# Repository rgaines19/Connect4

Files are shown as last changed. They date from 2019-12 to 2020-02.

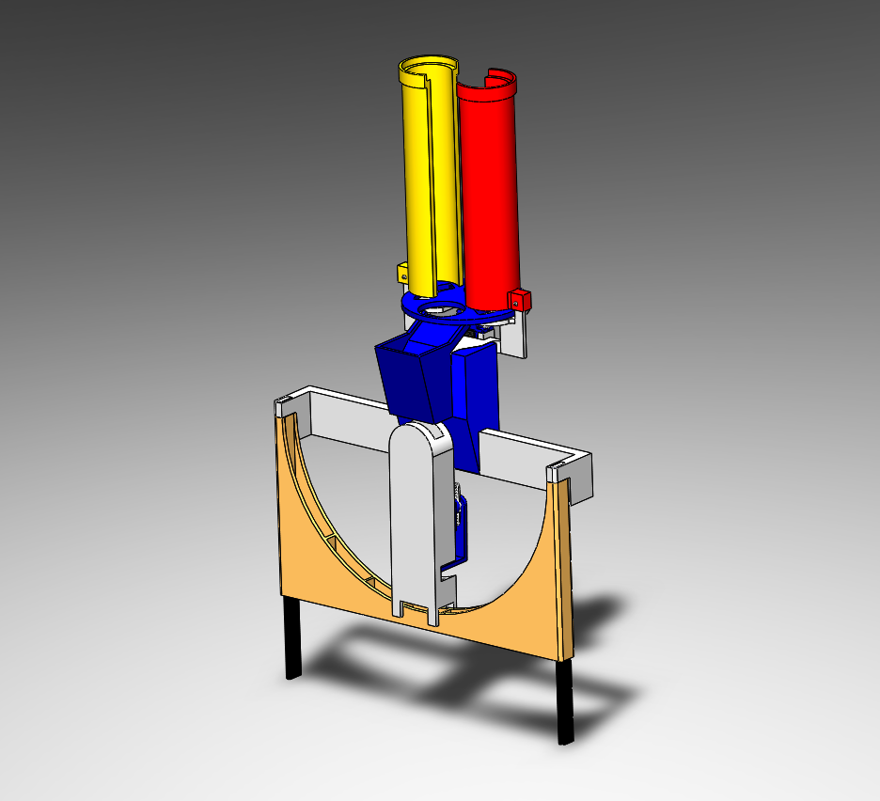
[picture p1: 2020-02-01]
Connect_4/Connect4_Robot.PNG

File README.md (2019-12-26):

# Connect4
This is a connect 4 project on arduino.
It will interface with an actual connect 4 gameboard by using push buttons and servos.

The game will have 3 difficultly levels.
Connect4.ino is the original C file for the game with 2 difficulties

Connect_4_Final_MEGA_Test_v2.ino is the complete working program that was used
at the Engineering Showcase.

Connect_4_Final_Due.ino is the program that has all three difficulty levels.
All it need is to port the servo commands and LED drivers and some status flags
to function properly.

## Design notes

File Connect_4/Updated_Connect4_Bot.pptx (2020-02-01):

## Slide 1

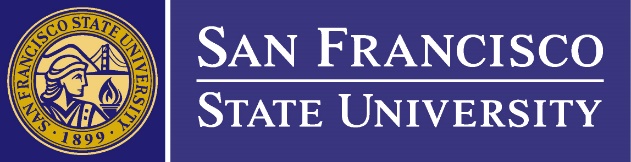
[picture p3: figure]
Image result

Connect 4 AI Bot
Team Members: Ronald Gaines (EE), Devin Perry (EE)
Academic Advisor: Dr. Thomas Holton

Introduction

This project arose from a conversation with a nurse that works in the children’s ward at UCSF. We decided to build a system that would brighten children’s days and get them curious about engineering.
Connect 4 is a two-player game where the objective is to connect four pieces in a row.

Objective

To create an AI-based robotic system to play against a human in Connect 4. It will be able to interact with a physical gameboard in order to provide a unique playing experience. In order to satisfy this objective, our system has to do the following:
- Detect when a human player makes a move
- Employ an AI algorithm to determine the system’s move
- Activate a robotic system to dispense game pieces into the correct column

Dispensing Mechanism

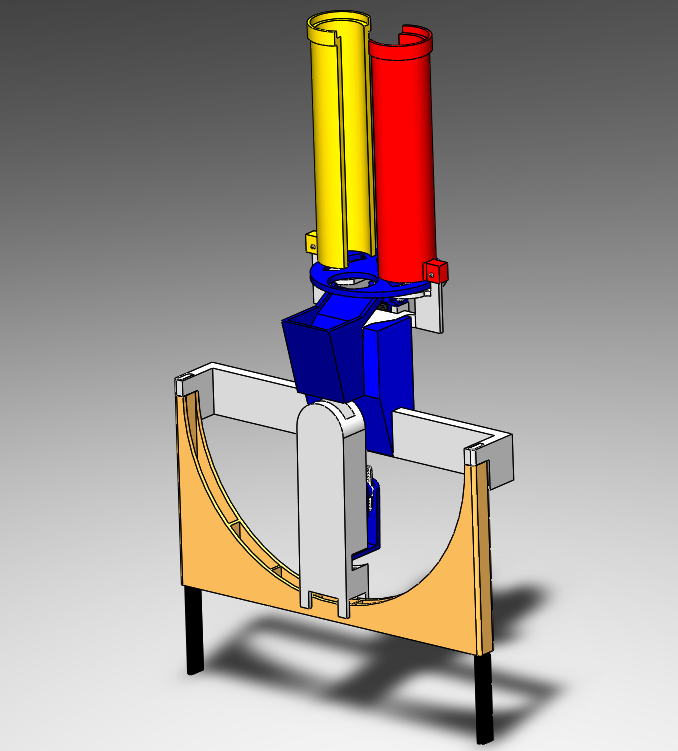
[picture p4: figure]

Flow Diagram

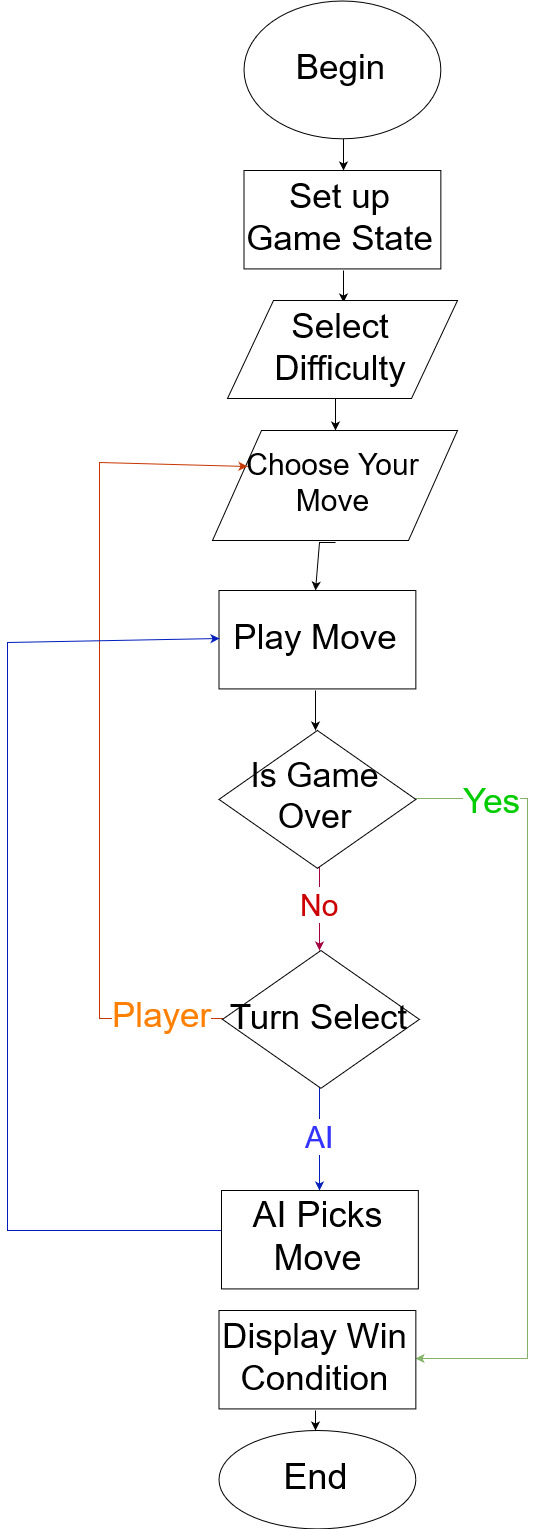
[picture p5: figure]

Discussion

- One the early problems we ran into was dealing with debouncing the arcade switches. Instead of debouncing seven signals, we used a 8:3 priority encoder to solve the problem. When sampling the button press, we send a signal to turn off the encoder which solved the bouncing problem.
- We had to switch from the Arduino Mega to the Arduino Due because the Mega didn’t have enough memory or computational power for our AI. The Due uses a 32 bit ARM processor.
- The dispensing mechanism was designed using SolidWorks, which allowed us to create the exact parts necessary.
- Manufacturing was done with 3D Printing in order to reduce costs and decrease time between design iterations.

Design

In order to meet our objective we used an Arduino Due. The Artificial Intelligence has 3 difficulty levels. The first level is a simple random number generator. The second level is our minimax algorithm with a search depth of 1. The third level is the minimax algorithm with a search depth of 4.
- We used arcade switches and LED’s for the human to interact with the game
- We 3D printed parts to create the dispensing mechanism
- We used 3 Servo motors to aid with dispensing the game pieces
- We used Minimax Algorithm with an evaluation function to create the AI system

Connectivity Diagram

AI Algorithm

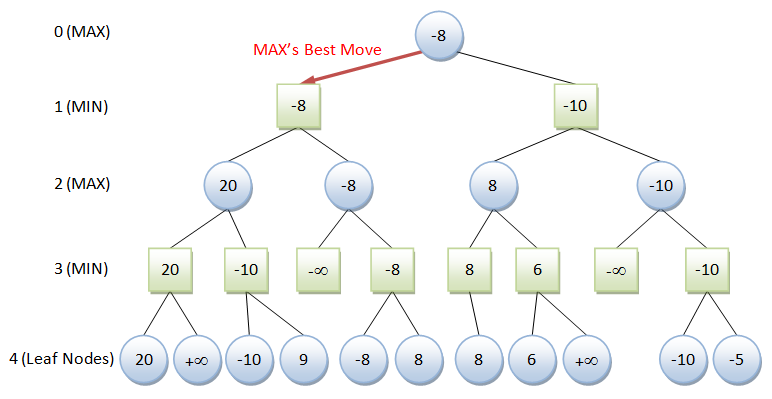
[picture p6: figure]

The minimax algorithm we used is a recursive AI algorithm for choosing the next move based on the position of the game pieces. The algorithm’s position evaluation determines how good each possible move is and attempts to minimize the possible maximum (worst-case) outcome. As the search depth increases, the better the AI’s decision becomes at the cost of computational time.

Future Work

- We would like to implement WIFI connectivity in order for two people to play each other from different rooms using two boards.
- We need to improve our evaluation functions to recognize some corner cases.
- We would like to implement Minimax algorithm with alpha-beta pruning in order to speed up the AI decision time.
- Implementing snap-fit connections would improve the building procedure of our dispensing mechanism
Acknowledgments: Our team would like to thank our advisor and mentor Dr. Holton for his assistance in the completion of this project.

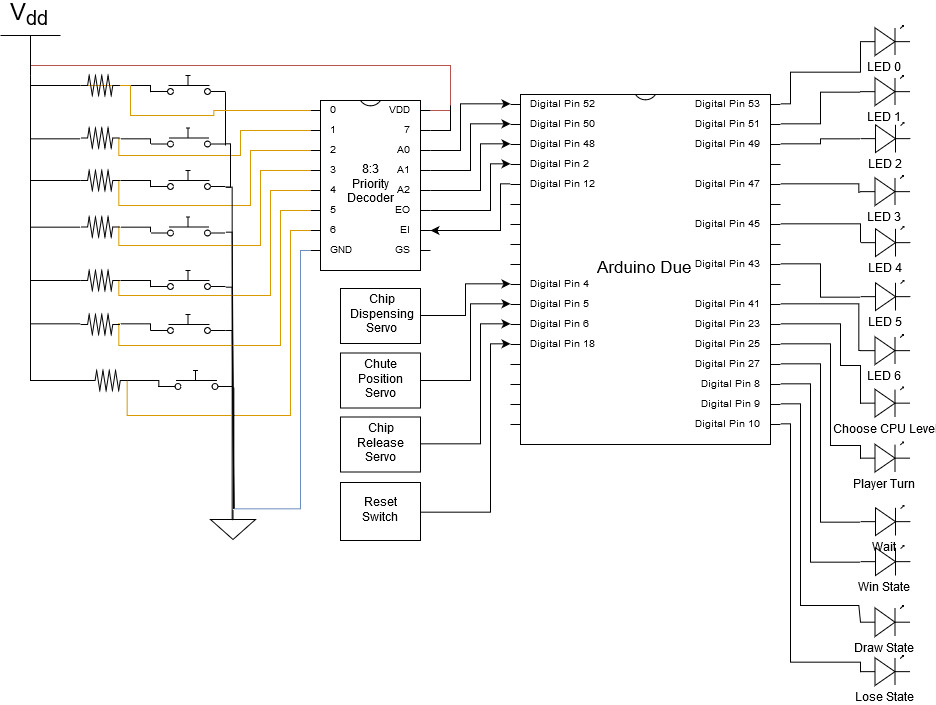
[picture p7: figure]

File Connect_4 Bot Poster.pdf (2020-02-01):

- We would like to implement WIFI connectivity in order for two people to play each other from different rooms using two boards.

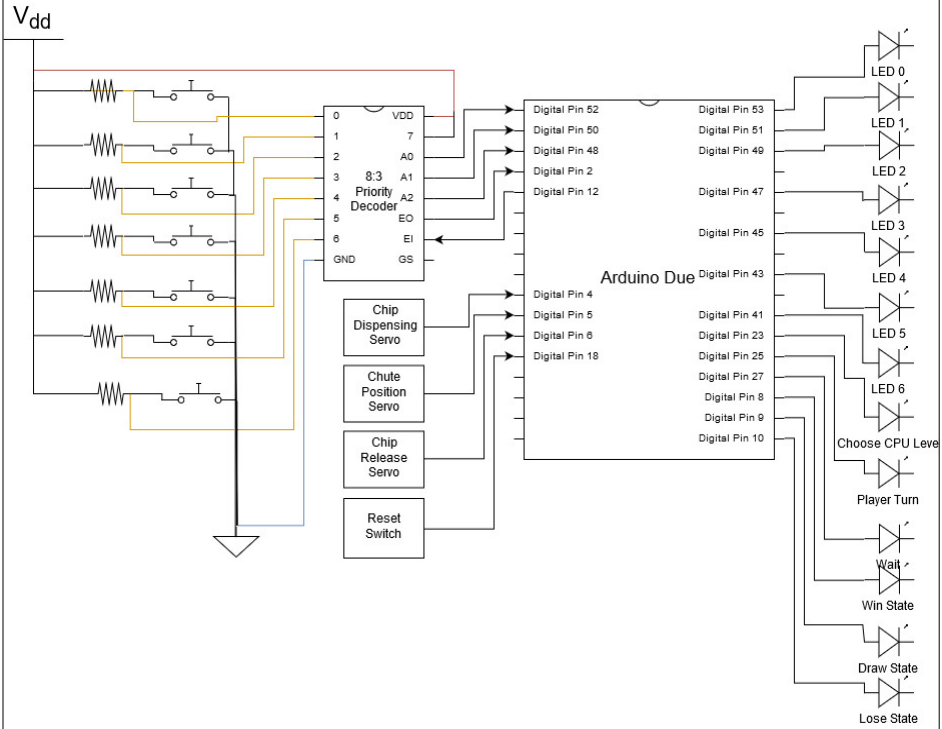
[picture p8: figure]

- We need to improve our evaluation functions to recognize some corner cases.
- We would like to implement Minimax algorithm with alpha-beta pruning in order to speed up the AI decision time.
- Implementing snap-fit connections would improve the building procedure of our dispensing mechanism

Acknowledgments: Our team would like to thank our advisor and mentor Dr. Holton for his assistance in the completion of this project.

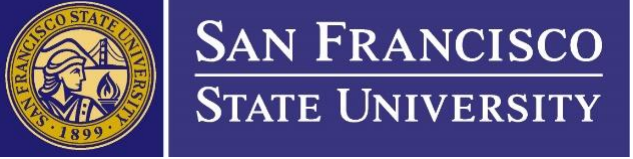
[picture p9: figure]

# Connect 4 AI Bot

Team Members: Ronald Gaines (EE), Devin Perry (EE) Academic Advisor: Dr. Thomas Holton

This project arose from a conversation with a nurse that works in the children’s ward at UCSF. We decided to build a system that would brighten children’s days and get them curious about engineering.
Connect 4 is a two-player game where the objective is to connect four pieces in a row.

In order to meet our objective we used an Arduino Due. The Artificial Intelligence has three difficulty levels.
The first level is a simple random number generator. The second level is our minimax algorithm with a search depth of one. The third level is the minimax algorithm with a search depth of four.
- We used arcade switches and LED’s for the human to interact with the game
- We 3D printed parts to create the dispensing mechanism
- We used three Servo motors to aid with dispensing the game pieces
- We used Minimax Algorithm with an evaluation function to create the AI system
- One the early problems we ran into was dealing with debouncing the arcade switches. Instead of debouncing seven signals, we used a 8:3 priority encoder to solve the problem. When sampling the button press, we send a signal to turn off the encoder which solved the bouncing problem.
- We had to switch from the Arduino Mega to the Arduino Due because the Mega didn’t have enough memory or computational power for our AI. The Due uses a 32-bit ARM processor.
- The dispensing mechanism was designed using SolidWorks, which allowed us to create the exact parts necessary.
- Manufacturing was done with 3D Printing in order to reduce costs and decrease time between design iterations.

## Design

## Introduction

To create an AI-based robotic system to play against a human in Connect 4. It will be able to interact with a physical gameboard in order to provide a unique playing experience. In order to satisfy this objective, our system has to do the following:

- Detect when a human player makes a move
- Employ an AI algorithm to determine the system’s move
- Activate a robotic system to dispense game pieces into the correct column

## Objective

## Discussion

## Future Work

Dispensing Mechanism | Flow Diagram

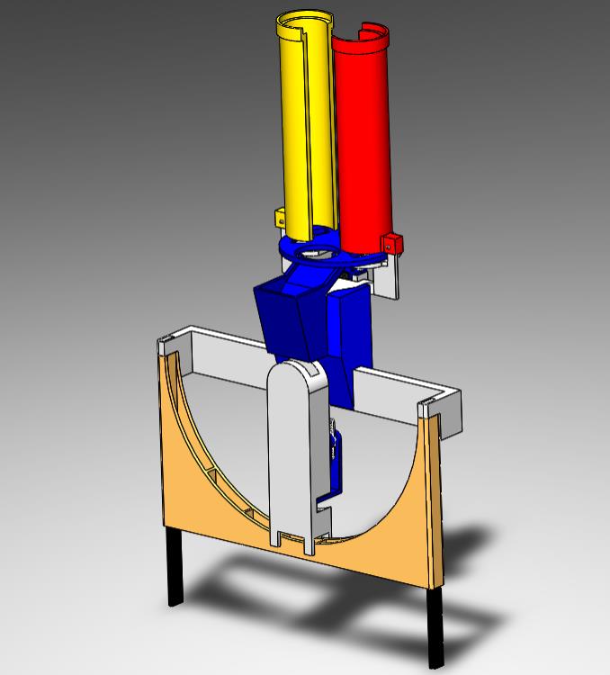
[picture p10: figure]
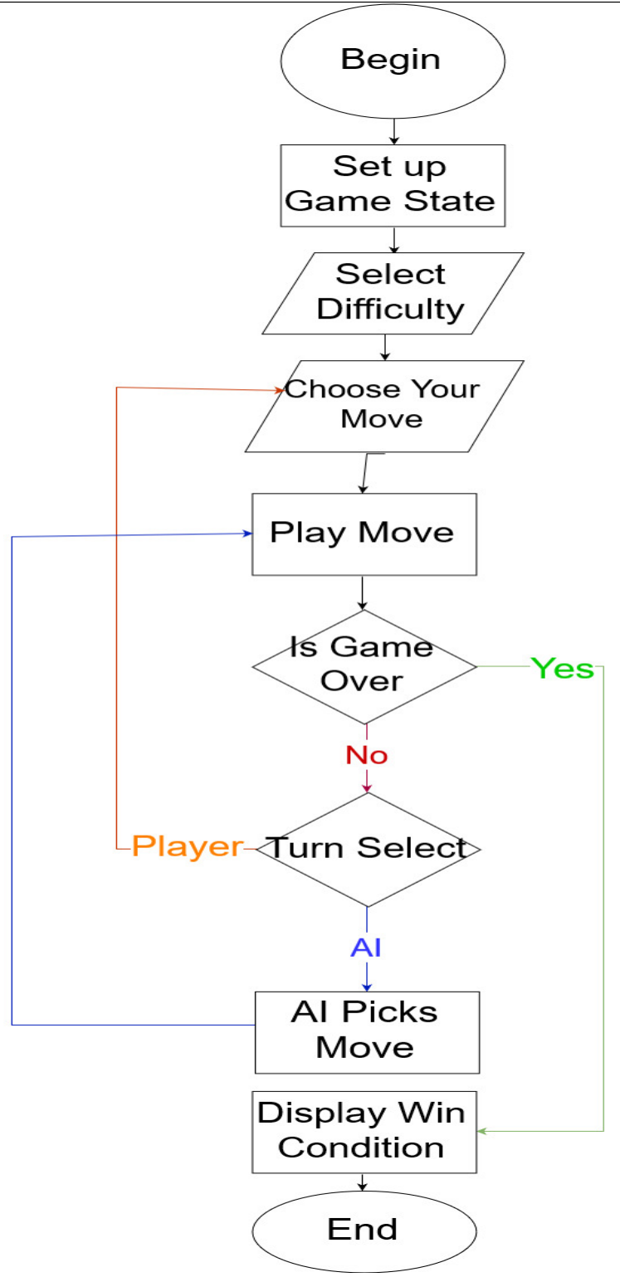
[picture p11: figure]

Connectivity Diagram | AI Algorithm

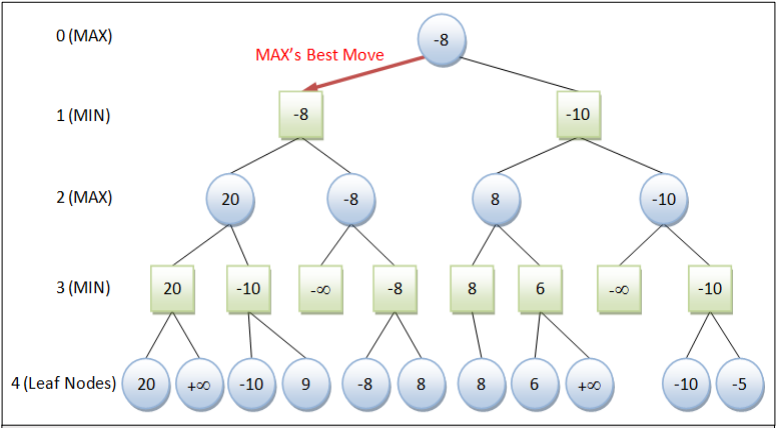
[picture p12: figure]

The minimax algorithm we used is a recursive AI algorithm for choosing the next move based on the position of the game pieces. The algorithm’s position evaluation determines how good each possible move is and attempts to minimize the possible maximum (worst-case) outcome. As the search depth increases, the better the AI’s decision becomes at the cost of computational time.

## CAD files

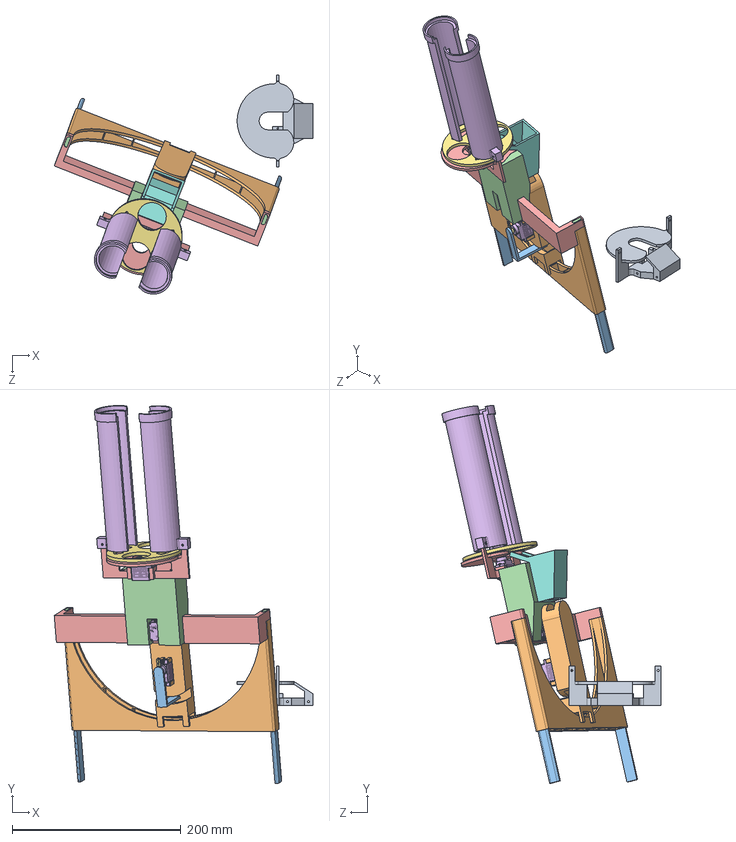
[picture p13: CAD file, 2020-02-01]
Connect_4/Connect4_Robot.SLDASM
306.7 x 448.4 x 260.1 mm
C4_Halfpipe
C4_Halfpipe Leg_NEW x 2
C4_ServoHolder Leg x 2
C4_ServoHolder
SG90 - Micro Servo 9g - Tower Pro.1 x 3
SG90 - Micro Servo 9g - Tower Pro.3 x 3
SG90 - Micro Servo 9g - Tower Pro.5 x 6
SG90 - Micro Servo 9g - Tower Pro.6 x 5
C4_Chute_3
C4_Gate
C4_Dispenser_Holder
Double_sided
Piece Holder Tube x 2
C4_Extractor
Slider Spacer Front

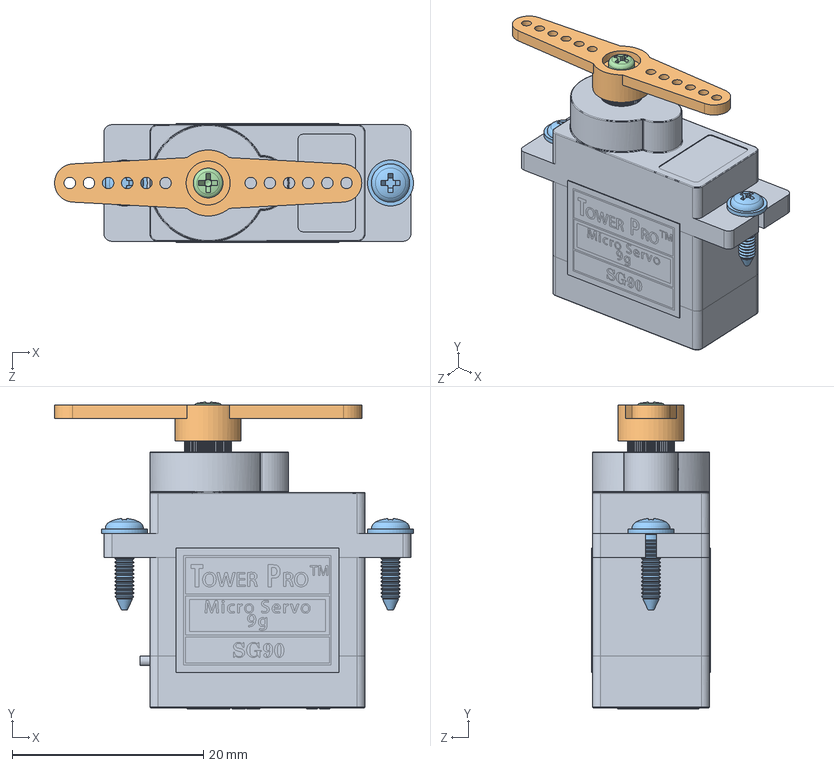
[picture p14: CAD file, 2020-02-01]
Connect_4/sg90-micro-servo-9g-tower-pro-1/SG90 - Micro Servo 9g - Tower Pro.SLDASM
37.5 x 32.0 x 12.4 mm
SG90 - Micro Servo 9g - Tower Pro.1
SG90 - Micro Servo 9g - Tower Pro.3
SG90 - Micro Servo 9g - Tower Pro.5 x 2
SG90 - Micro Servo 9g - Tower Pro.6

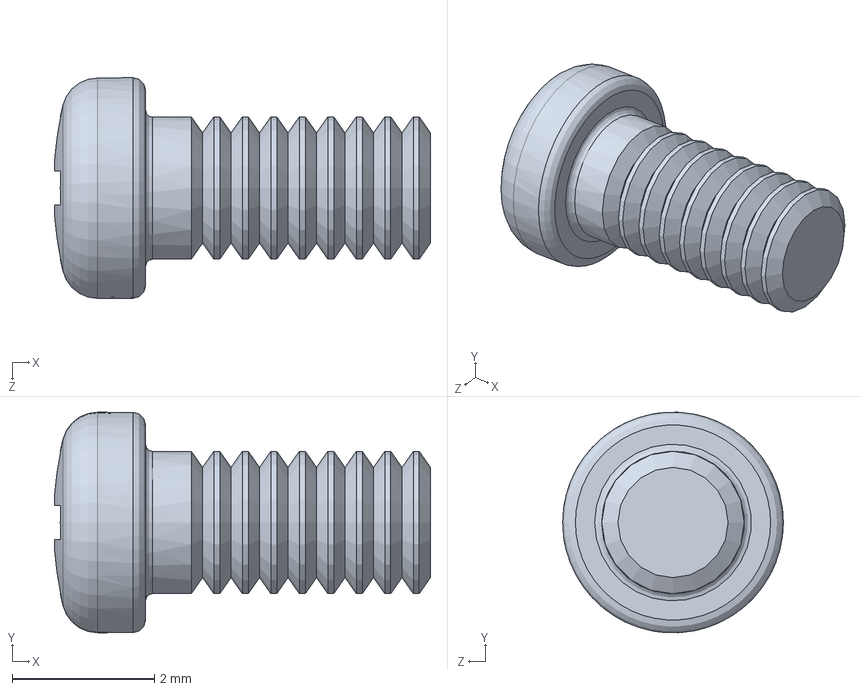
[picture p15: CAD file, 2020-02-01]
Connect_4/sg90-micro-servo-9g-tower-pro-1/SG90 - Micro Servo 9g - Tower Pro.6.SLDPRT
5.28 x 3.10 x 3.10 mm

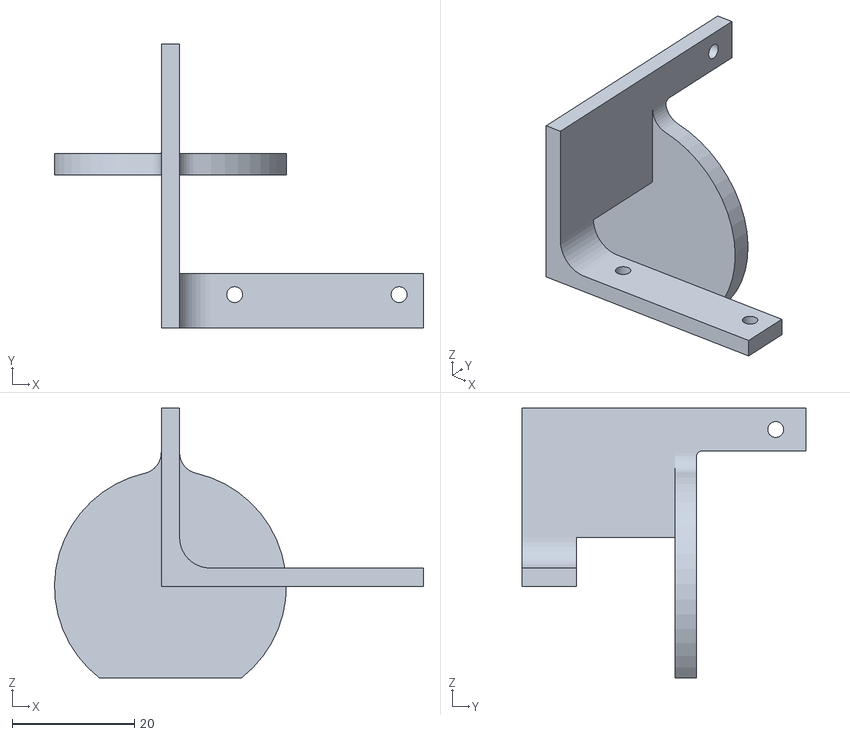
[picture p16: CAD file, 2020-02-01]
Connect_4/STL/C4_Piece Holder.STL
60.5 x 46.6 x 44.2

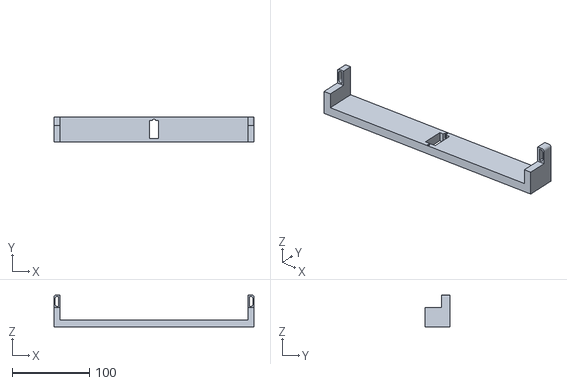
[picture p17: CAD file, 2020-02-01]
Connect_4/STL/C4_ServoHolder.STL
259.6 x 32.6 x 41.3

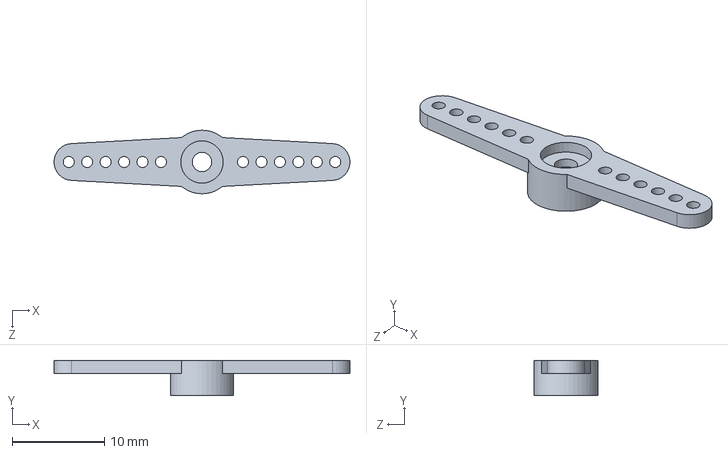
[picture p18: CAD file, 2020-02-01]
Connect_4/sg90-micro-servo-9g-tower-pro-1/SG90 - Micro Servo 9g - Tower Pro.3.SLDPRT
32.1 x 3.80 x 6.90 mm

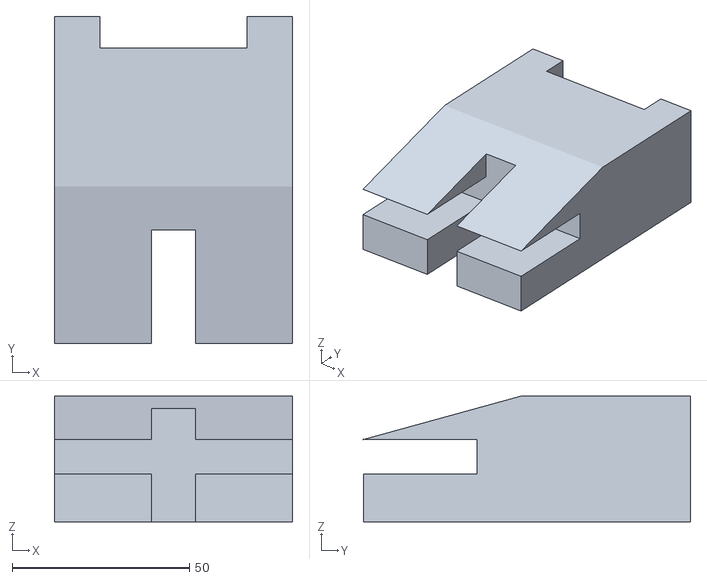
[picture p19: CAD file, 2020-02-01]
Connect_4/STL/C4_Dispenser_Holder.STL
67.1 x 92.3 x 35.4

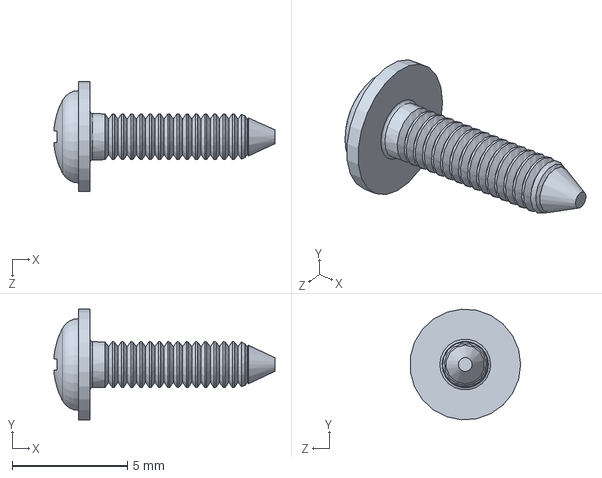
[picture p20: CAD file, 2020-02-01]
Connect_4/sg90-micro-servo-9g-tower-pro-1/SG90 - Micro Servo 9g - Tower Pro.5.SLDPRT
9.57 x 4.79 x 4.78 mm

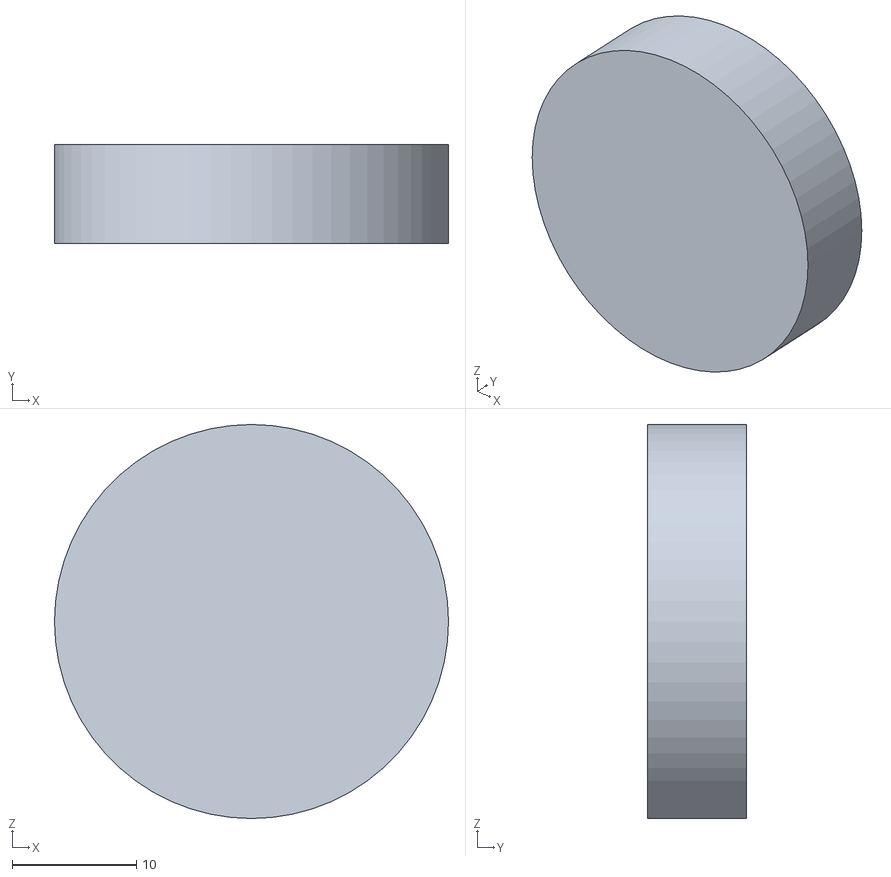
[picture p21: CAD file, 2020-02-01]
Connect_4/STL/Chip.STL
31.8 x 7.94 x 31.8

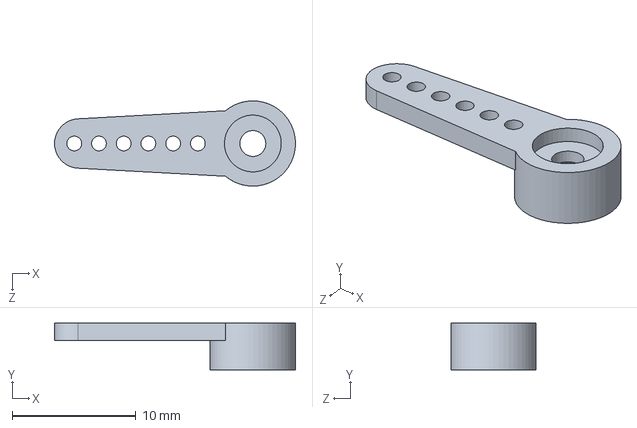
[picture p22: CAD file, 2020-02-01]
Connect_4/sg90-micro-servo-9g-tower-pro-1/SG90 - Micro Servo 9g - Tower Pro.2.SLDPRT
19.5 x 3.80 x 6.90 mm

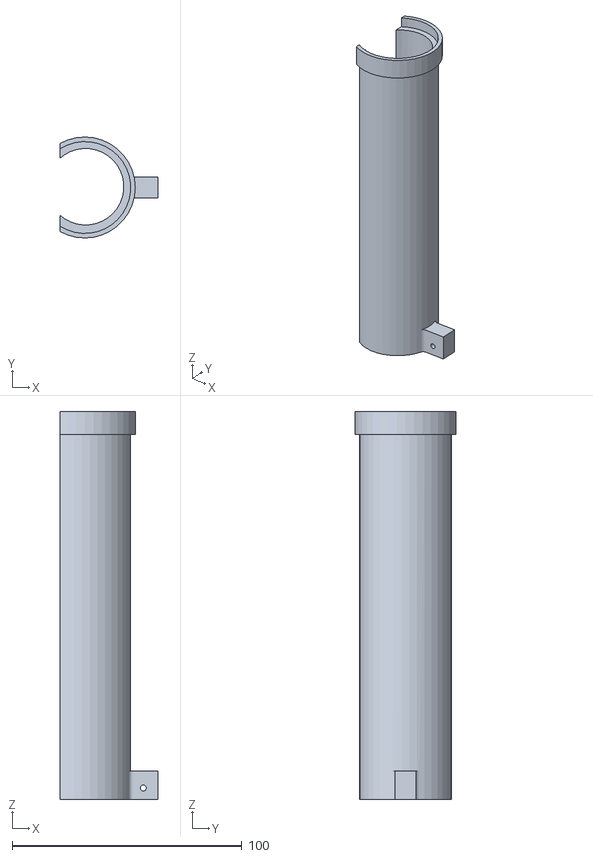
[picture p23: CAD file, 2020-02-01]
Connect_4/STL/C4_Piece Holder Tube.STL
42.9 x 44.0 x 169.0

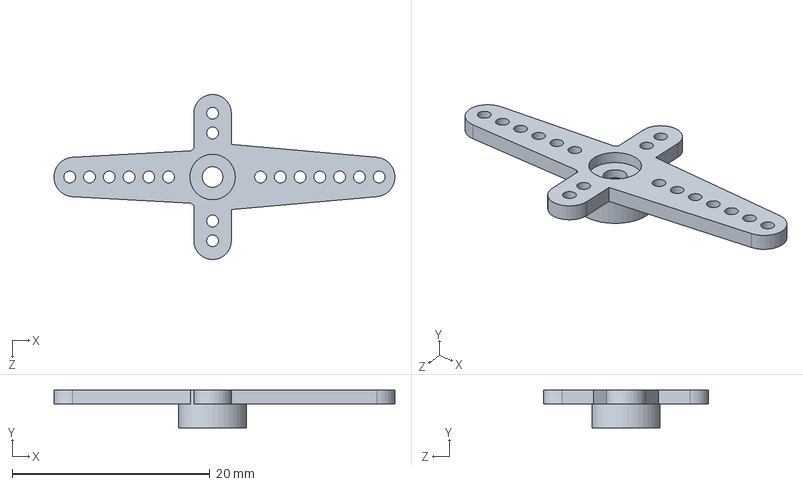
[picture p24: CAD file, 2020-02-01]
Connect_4/sg90-micro-servo-9g-tower-pro-1/SG90 - Micro Servo 9g - Tower Pro.4.SLDPRT
34.5 x 3.80 x 16.7 mm

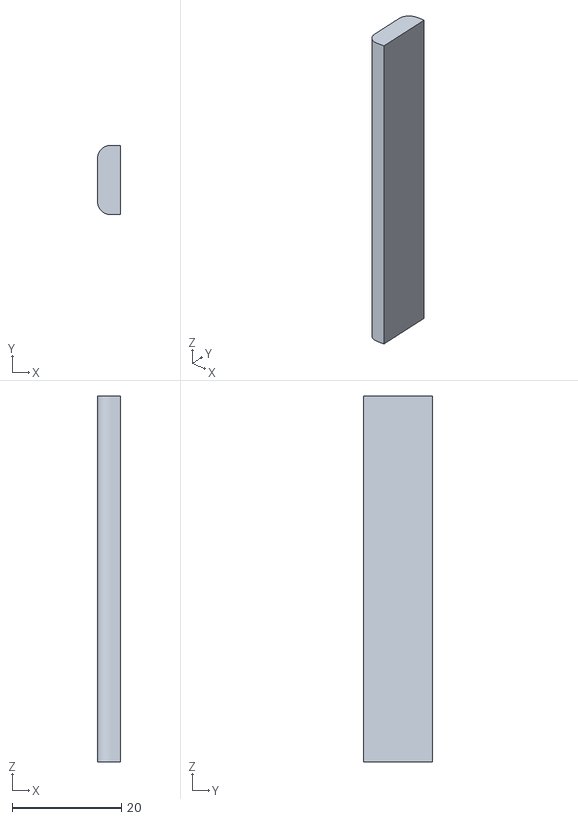
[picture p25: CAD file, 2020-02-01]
Connect_4/STL/C4_ServoHolder Leg.STL
4.25 x 12.7 x 66.9

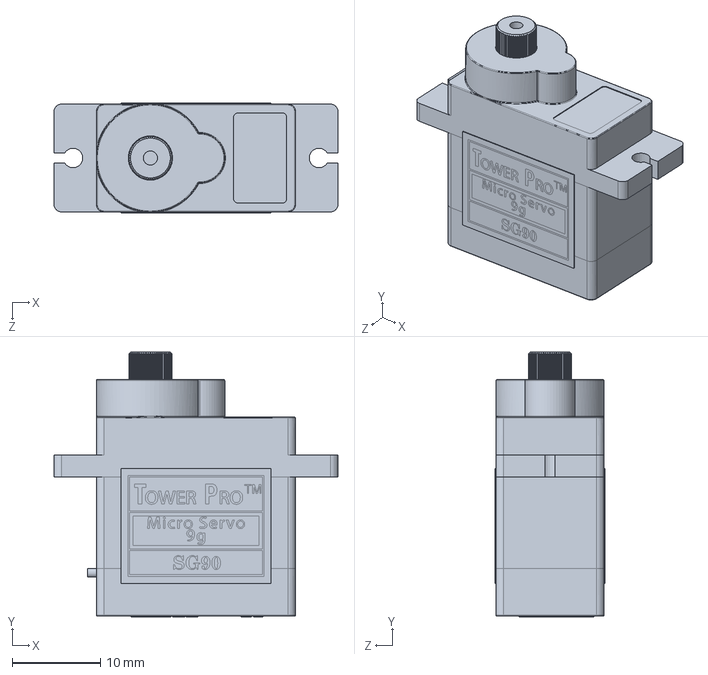
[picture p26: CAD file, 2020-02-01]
Connect_4/sg90-micro-servo-9g-tower-pro-1/SG90 - Micro Servo 9g - Tower Pro.1.SLDPRT
32.1 x 30.0 x 12.4 mm

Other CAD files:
Connect_4/STL/C4_Halfpipe Leg_NEW.STL
Connect_4/STL/C4_Gate.STL
Connect_4/STL/C4_Chip_Ramp.STL
Connect_4/STL/Double_sided.STL
Connect_4/STL/C4_Chute_3.STL
Connect_4/STL/C4_Extractor.STL
Connect_4/STL/C4_Halfpipe Leg.STL
Connect_4/STL/C4_Halfpipe.STL
Connect_4/STL/C4_Halfpipe_without_legs.STL
Connect_4/STL/Double_sided_THICK.STL
Connect_4/sg90-micro-servo-9g-tower-pro-1/SG90 - Micro Servo 9g - Tower Pro.x_t

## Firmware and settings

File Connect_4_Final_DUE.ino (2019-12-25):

#include <Servo.h>

int state = 0;
int next_state = 0;
const int ROW = 6;
const int COL = 7;
const int VERTICAL_WIN_STATES = 21;
const int HORIZONTAL_WIN_STATES = 24;
const int DIAGANOL_WIN_STATES = 12;
const int PLAYER_1_WIN = 4;
const int PLAYER_2_WIN = -4;
const int PLAYER_1_PIECE = 1;
const int PLAYER_2_PIECE = -1;
const int ALPHA_INIT = -2147483648; // smallest 32 bit number ie 2^31
const int BETA_INIT = 2147483647;   // largest  32 bit number 2^31 -1
int level = 1;
int turn = 1;

struct game{
  int gameboard[ROW][COL];
  int colToken[COL];
};

struct minmax_vars{
    int column;
    int value;
};

struct score_vectors{
    int verSum[VERTICAL_WIN_STATES];
    int horSum[HORIZONTAL_WIN_STATES];
    int posDiagSum[DIAGANOL_WIN_STATES];
    int negDiagSum[DIAGANOL_WIN_STATES];
};

void setup() {
  // put your setup code here, to run once:
  Serial.begin(9600);
}

void loop() {
  // put your main code here, to run repeatedly:
  state = next_state;
  switch (state){
    case 0: //set up game state



      next_state = 1;
      break;
    case 1: // pick cpu level


      next_state = 2;
      break;
    case 2: // player pick move



      next_state = 3;
      break;
    case 3: // play moves using servo comands
      break;
    case 4: // check the win state 
      break;
    case 5: // AI picks its move
      break;
    case 6: // goes to this state when the game is over
      next_state = 6;
      break;
    default: // if error in the program go to state 6
      next_state = 6;
      break;
  }
}

struct game createGame(void){
  struct game g;
  for(int a =0; a < ROW; a++){
    for(int b = 0; b < COL; b++){
      g.gameboard[a][b] = 0;
    }
  }

  for(int i = 0; i<COL; i++){
    g.colToken[i] = 5;
  }
  return g;
}

struct game copygame(struct game g){
  struct game g1;
  for(int a =0; a < ROW; a++){
    for(int b = 0; b < COL; b++){
      g1.gameboard[a][b] = g.gameboard[a][b];
    }
  }

  for(int i = 0; i<COL; i++){
    g1.colToken[i] = g.colToken[i];
  }
  return g;
}

bool checkWinState(struct game g, struct score_vectors s, int playerPiece){
    bool win = false;
    int check_value;
    if(playerPiece == PLAYER_2_PIECE){
        check_value = PLAYER_2_WIN;
    }
    else{
        check_value = PLAYER_1_WIN;
    }
    for (int now = 0; now <VERTICAL_WIN_STATES; now++) {
        if (s.verSum[now] == check_value){
            win = true;
            break;
        }
    }
    
    for (int now = 0; now <HORIZONTAL_WIN_STATES; now++) {
        if(s.horSum[now] == check_value){
            win = true;
            break;
        }
    }

    
    for (int now = 0; now <DIAGANOL_WIN_STATES; now++) {
        if(s.posDiagSum[now] == check_value){
            win = true;
            break;
        }
    }

    
    for (int now = 0; now <DIAGANOL_WIN_STATES; now++) {
        if(s.negDiagSum[now] == check_value){
            win = true;
            break;
        }
    }

    return win;
}
struct game playMove(struct game g,int col, int playerPiece){
    g.gameboard[g.colToken[col]][col] = playerPiece;
    g.colToken[col]--;
    return g;
}

struct score_vectors evalBoard(struct game g, struct score_vectors s){
    int count = 0;
    
    // vertical check function
    for (int x = 0; x < 7; x++) {
        for (int y =0; y<3; y++) {
            s.verSum[count] = g.gameboard[y][x]+g.gameboard[y+1][x]+g.gameboard[y+2][x]+g.gameboard[y+3][x];
            count++;
        }
    }
    count = 0;
    // horizontal check function
    for (int x = 0; x < 6; x++) {
        for (int y =0; y<4; y++) {
            s.horSum[count] = g.gameboard[x][y]+g.gameboard[x][y+1]+g.gameboard[x][y+2]+g.gameboard[x][y+3];
            count++;
        }
    }
    count = 0;
    // Positive Edge Diagnol check function
    for(int r =0; r < 3; r++){
        for (int c =0; c <4; c++) {
            s.posDiagSum[count] = g.gameboard[r][c] + g.gameboard[r+1][c+1] + g.gameboard[r+2][c+2] + g.gameboard[r+3][c+3];
            count++;
        }
    }
    count = 0;
    // Negative Edge Diagnol check function
    for(int r =0; r < 3; r++){
        for (int c = 6; c > 2; c--) {
            s.negDiagSum[count] = g.gameboard[r][c] + g.gameboard[r+1][c-1] + g.gameboard[r+2][c-2] + g.gameboard[r+3][c-3];
            count++;
        }
    }
    return s;
}

void printBoard(struct game g){
    for (int m=0; m<ROW; m++) {
        for (int n=0; n<COL; n++) {
            printf("%4d ", g.gameboard[m][n]);
        }
        printf("\n");
    }
}


int AIpickMove(struct game g, struct score_vectors s){
    int col =0;
    struct minmax_vars m;
    m.column =0;
    m.value =0;
    switch (level){
      case 1:
        col = AIrandMove(g);
        break;
      case 2:
        m = minimax(g,1,true,m,s);
        col = m.column;
        break;
      case 3:
        m = minimax(g,4,true,m,s);
        col = m.column;
        break;
      default:
      break;
    }
    
    return col;
}

int scoreBoard(struct game g,struct score_vectors s,int playerPiece){
    int score = 0;
    int center_column_count = 0;
    int player = 1;
    if (playerPiece == PLAYER_2_PIECE) {
        player = -1;
    }
 
    for (int i = 0; i<ROW; i++) {
        if (g.gameboard[i][3]== 1*player) {
            center_column_count++;
        }
    }
    score += center_column_count*1000;
        
        for (int x =0; x<24; x++) {
            if (s.horSum[x]==4*player) {
                score+=100000;
            }
            if (s.horSum[x]==3*player) {
                score+=0;
            }
            if (s.horSum[x]==2*player) {
                score+=0;
            }
            
            if (s.horSum[x]==(-2)*player) {
                score-=500;
            }
             
            
            if (s.horSum[x]==(-3)*player) {
                score-=10000;
            }
            
            if (s.horSum[x]==(-4)*player) {
                score-=1000000000;
            }
            
        }
        
        for (int x =0; x<21; x++) {
            if (s.verSum[x]==4*player) {
                score+=100000;
            }
            if (s.verSum[x]==3*player) {
                score+=0;
            }
            if (s.verSum[x]==2*player) {
                score+=0;
            }
            
            if (s.verSum[x]==(-2)*player) {
                score-=1000;
            }
            
            if (s.verSum[x]==(-3)*player) {
                score-=10000;
            }
            if (s.verSum[x]==(-4)*player) {
                score-=1000000000;
            }
        }
        for (int x =0; x<12; x++) {
            if (s.posDiagSum[x]==4*player) {
                score+=100000;
            }
            if (s.posDiagSum[x]==3*player) {
                score+=0;
            }
            if (s.posDiagSum[x]==2*player) {
                score+=0;
            }
            
            if (s.posDiagSum[x]==-2*player) {
                score-=1000;
            }
            
            if (s.posDiagSum[x]==(-3)*player) {
                score-=10000;
            }
            if (s.posDiagSum[x]==(-4)*player) {
                score-=1000000000;
            }
        }
        for (int x =0; x<12; x++) {
            if (s.negDiagSum[x]==4*player) {
                score+=100000;
            }
            if (s.negDiagSum[x]==3*player) {
                score+=0;
            }
            if (s.negDiagSum[x]==2*player) {
                score+=0;
            }
            
            if (s.negDiagSum[x]==(-2)*player) {
                score-=1000;
            }
             
            if (s.negDiagSum[x]==(-3)*player) {
                score-=10000;
            }
            if (s.negDiagSum[x]==(-4)*player) {
                score-=1000000000;
            }
            
        }
        
    
    return score;
    
}

bool valid_moves_left(struct game g){
    bool valid = false;
    int count = 0;
    for (int i =0; i < COL; i++) {
        if (g.colToken[i] == -1) {
            count++;
        }
        
    }
    if (count == 7) {
        valid = true;
    }
    return valid;
}

bool is_terminal_node(struct game g, struct score_vectors s){
    bool winstate = false;
    bool cek1 = checkWinState(g, s, PLAYER_1_PIECE);
    bool cek2 = checkWinState(g, s, PLAYER_2_PIECE);
    bool cek3 = valid_moves_left(g);
    if (cek1 || cek2 ||cek3 ) {
        winstate = true;
    }
            return winstate;
}

        
    struct score_vectors createScoreVectors(struct score_vectors s){
        for (int j = 0; j<24; j++) {
            if (j<21) {
                s.verSum[j] =0;
            }
            if (j<12){
                s.posDiagSum[j] = 0;
                s.negDiagSum[j] = 0;
            }
            s.horSum[j]=0;
        }
        return s;
    }
struct minmax_vars minimax(struct game g,int depth, bool maximizingPlayer, struct minmax_vars m,struct score_vectors s){

bool is_terminal = is_terminal_node(g,s);
if ((depth <= 0) ||  (is_terminal == true)) {
    if (is_terminal == true) {
        if (checkWinState(g, s, PLAYER_1_PIECE) == true) {
            m.value = -100000000;
            //printf("The score is: %d\n", m.value);
            return m;
        }
    
        else if((checkWinState(g, s, PLAYER_2_PIECE) == true)){
            m.value = 100000000;
            //printf("The score is: %d\n", m.value);
            return m;
        }
        else {
            m.value = 0;
            return m;
        }
    }else{
        s = evalBoard(g, s);
        m.value = scoreBoard(g,s,PLAYER_2_PIECE);
        //printf("The score is: %d\n",m.value);
        return m;
    }
}
    if (maximizingPlayer == true) {
        int value = ALPHA_INIT;
        for (int col = 0; col < COL; col++) {
            if (g.colToken[col] > -1 && g.colToken[col] < 6) {
                struct game board_copy;
                board_copy = copygame(g);
                board_copy = playMove(board_copy, col, PLAYER_2_PIECE);
                s = evalBoard(board_copy, s);
                //printf("\n");
                //printBoard(board_copy);
                m = minimax(board_copy, depth-1, false, m,s);
                if (m.value > value) {
                    value = m.value;
                    m.column = col;
                }
               
            }
            
        }
        return m;
    }
    else
    {
        int value = BETA_INIT;
        for (int col = 0; col < COL; col++) {
            if (g.colToken[col] > -1 && g.colToken[col] < 6) {
                struct game board_copy;
                board_copy = copygame(g);
                board_copy = playMove(board_copy, col, PLAYER_1_PIECE);
                s = evalBoard(board_copy, s);
                //printf("\n");
                //printBoard(board_copy);
                m = minimax(board_copy, depth-1,true, m,s);
                if (m.value < value) {
                    value = m.value;
                    m.column = col;
                }
                
            }
            else{
                //printf("column full\n");
            }
            
        }
        return m;
    }
}
int AIrandMove(struct game g){
    //int col = rand() % 7;
    int col = random(0,7);
    bool validmove = false;
    while (validmove == false) {
        col = random(0,6);
        //col = rand()%7;
        validmove = isMoveValid(col, g);
    }
    return col;
}

bool isMoveValid(int move, struct game g){
    bool Check;
    int col = g.colToken[move];
    if (col <  0  || col > 5) {
        Check = false;
        
    }
    else{
        Check = true;
    }
    return Check;
}

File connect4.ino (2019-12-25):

//
//  main.c
//  connect 4 made in c
//
//  Created by Ron Gaines on 9/4/19.
//  Copyright © 2019 Ron Gaines. All rights reserved.
//

#include <stdio.h>
#include <string.h>
#include <stdbool.h>

int colToken[7] = {5,5,5,5,5,5,5};
int gameboard[6][7];
int M = 6;
int N = 7;
int turn = 1;
int pushButton = 2;
int pushButton1 = 7;
int pushButton2 = 8;
int pushButton3 = 9;
int pushButton4 = 10;
int pushButton5 = 11;
int pushButton6 = 12;
int pushButton7 = 13;
volatile byte stateVector[7] = {HIGH,HIGH,HIGH,HIGH,HIGH,HIGH,HIGH};

//int StateVector[7] = {state0, state1, state2,state3,state4,state5,state6};

int verSum[21];
int horSum[24];
int posDiagSum[12];
int negDiagSum[12];
bool winState = false;

bool isMoveValid(int move);
bool checkWinState(void);

int pickMove(void);
void playMove(int move);
void printBoard(void);
void createBoard(void);
void evalBoard(void);
void printScoreVectors(void);
void createScoreVectors(void);
int rand(void);
int AIpickMove(void);

void setup() {
  randomSeed(analogRead(0));
  Serial.begin(9600);
  pinMode(pushButton, INPUT);
  pinMode(pushButton1, INPUT);
  pinMode(pushButton2, INPUT);
  attachInterrupt(digitalPinToInterrupt(pushButton), collect, FALLING);
}

void loop(void) {
    createBoard();
    createScoreVectors();
    evalBoard();
    printBoard();
    
    int size = 0;
    size = sizeof(gameboard);
    //Serial.print("The size of this board in memory is %d bytes", size);
    //Serial.print("\n");

    while (turn < 45) {
        // Game becomes a draw when turn counter hits
        if (turn == 45) {
            Serial.print("The Game is a draw.");
            break;
        }
    
    int move;
            if (turn % 2 == 0) {
            move = AIpickMove();
            playMove(move);
            Serial.print("the CPU move is: ");
            Serial.print(move, DEC);
            Serial.println();
            
        }
        else{
            bool PlayerMove = false;
            while(PlayerMove == false){
              move = pickMove();
              PlayerMove = isMoveValid(move);
              delay(100);
            }
            
            Serial.print("your move is: ");
            Serial.print(move, DEC);
            Serial.println();
            playMove(move);
        }
    
    printBoard();   
    
    Serial.print("The token at column ");
    Serial.print(move, DEC);
    Serial.print("is: ");
    Serial.print(colToken[move],DEC);
    Serial.println();
    evalBoard();
    //printScoreVectors();
    winState = checkWinState();
        if (winState == true) {
            if (turn % 2 == 0) {
                Serial.print("Player one won!!!\n");
            }
            else{
              Serial.print("The CPU won!!!\n");
            }
            
            break;
        }
    
    }
    
    return 0;
}

void collect(void){
    stateVector[0] = digitalRead(pushButton1);
    stateVector[1] = digitalRead(pushButton2);
    stateVector[2] = HIGH;
    stateVector[3] = HIGH;
    stateVector[4] = HIGH;
    stateVector[5] = HIGH;
    stateVector[6] = HIGH;
}

bool isMoveValid(int move){
    bool Check;
    int col = colToken[move];
    if (col <  0  || col > 5) {
        Check = false;
        
    }
    else{
        Check = true;
    }
    return Check;
}

int pickMove(void){
    int col = -1;
    //bool Check;
    
    //printf("Enter a column: ");
    //scanf("%d", &col);
    for(int m = 0; m < 7; m++){
      if(stateVector[m] == 0){
        col = m;
      }
    }
    //Check = isMoveValid(col);
    /*
    while (Check == false) {
        printf("Your pick is not valid.\n Enter a column: ");
        scanf("%d", &col);
        Check = isMoveValid(col);
    
    while (col < 0 || col > 6) {
        printf("Your pick is not valid.\n Enter a column: ");
        scanf("%d", &col);
        Check = isMoveValid(col);
        
    }
    
    }
   */ 
    return col;
}

void playMove(int move){
    if (turn % 2 == 0) {
        gameboard[colToken[move]][move] = -1;
    }
    else{
        gameboard[colToken[move]][move] = 1;
        resetStateVector(move);
    }
    
    colToken[move]--;
    turn++;
}

void printBoard(void){
    for (int m=0; m<M; m++) {
        for (int n=0; n<N; n++) {
            
            if(gameboard[m][n] == 0 || gameboard[m][n] == 1){
             Serial.print(" "); 
            }
            Serial.print(gameboard[m][n], DEC);
        }
        Serial.println();
    }
}
 
void createBoard(void){
    for (int a=0; a<M; a++) {
        for (int b=0; b<N; b++) {
            gameboard[a][b] = 0;
        } 
    }
}

void evalBoard(void){
    int count = 0;
    
    
    // vertical check function
    for (int x = 0; x < 7; x++) {
        for (int y =0; y<3; y++) {
            verSum[count] = gameboard[y][x]+gameboard[y+1][x]+gameboard[y+2][x]+gameboard[y+3][x];
            count++;
        }
    }
    count = 0;
    // horizontal check function
    for (int x = 0; x < 6; x++) {
        for (int y =0; y<4; y++) {
            horSum[count] = gameboard[x][y]+gameboard[x][y+1]+gameboard[x][y+2]+gameboard[x][y+3];
            count++;
        }
    }
    count = 0;
    // Positive Edge Diagnol check function
    for(int r =0; r < 3; r++){
        for (int c =0; c <4; c++) {
            posDiagSum[count] = gameboard[r][c] + gameboard[r+1][c+1] + gameboard[r+2][c+2] + gameboard[r+3][c+3];
            count++;
        }
    }
    count = 0;
    // Negative Edge Diagnol check function
    for(int r =0; r < 3; r++){
        for (int c = 6; c > 2; c--) {
            negDiagSum[count] = gameboard[r][c] + gameboard[r+1][c-1] + gameboard[r+2][c-2] + gameboard[r+3][c-3];
            count++;
        }
    }
}
void createScoreVectors(void){
    for (int j = 0; j<24; j++) {
        if (j<21) {
            verSum[j] =0;
        }
        if (j<12){
            posDiagSum[j] = 0;
            negDiagSum[j] = 0;
        }
        horSum[j]=0;
    }
}

void printScoreVectors(void){
    for (int now = 0; now <21
         ; now++) {
        printf("%d ",verSum[now]);
    }
    printf("\n");
    for (int now = 0; now <24; now++) {
        printf("%d ",horSum[now]);
    }
    printf("\n");
    
    for (int now = 0; now <12; now++) {
        printf("%d ",posDiagSum[now]);
    }
    printf("\n");
    
    for (int now = 0; now <12; now++) {
        printf("%d ",negDiagSum[now]);
    }
    printf("\n");

}
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
